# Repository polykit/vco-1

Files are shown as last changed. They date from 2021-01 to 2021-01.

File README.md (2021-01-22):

# Polykit VCO-1

This repository contains schematics and PCB layout for a voltage controlled oscillator (VCO). The goal was to keep price and component count low while having a good 1V/oct tracking. The oscillator core is roughly bases on the Jupiter 8 with a simpler approach for the current sink. It either needs a pair of matched 2N3904 transistors or one BC847BS dual transistor. I have very good results with the BC847BS and an accurate tracking over several octaves. On the output it generates a ramp and a pulse signal with 10Vpp amplitude. There is also a CV input for pulse width modulation.

Note: PCB also contains a simple sub-oscillator with output for one and two octaves down

There is also a PCB version with [eight oscillators on it](https://github.com/polykit/vco-8).

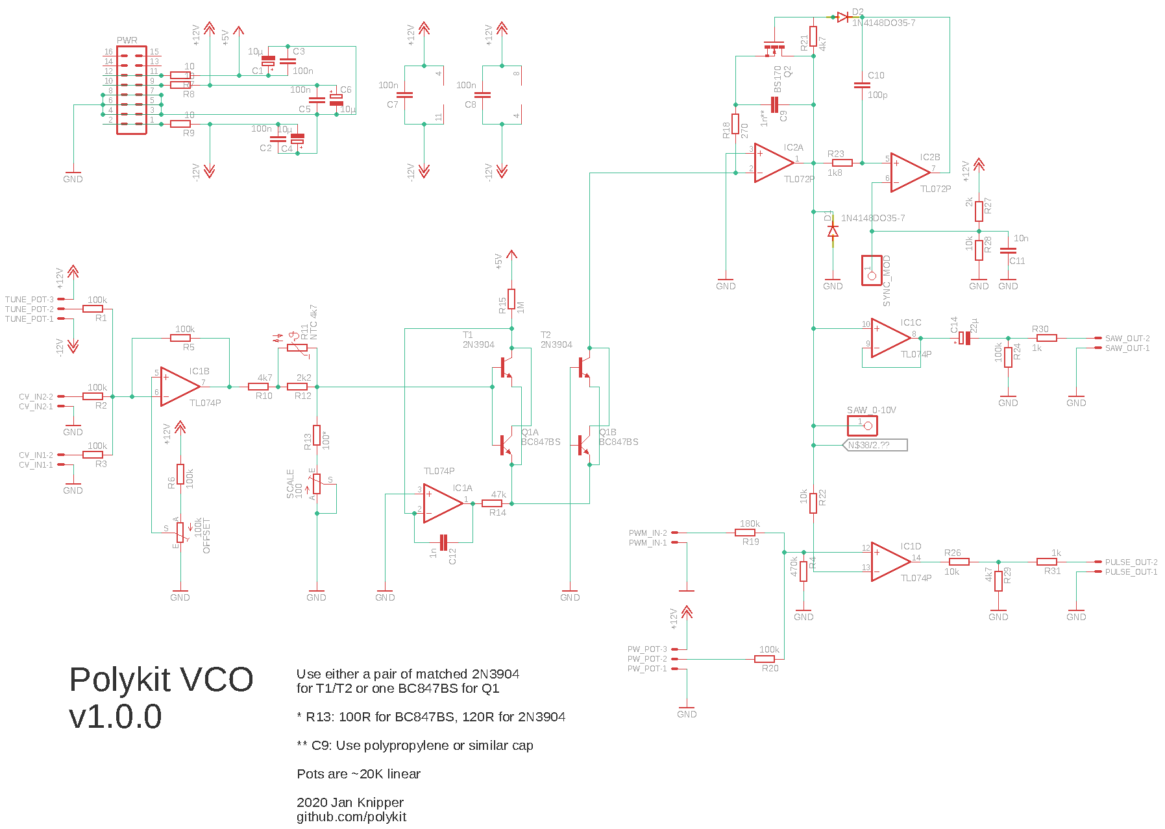
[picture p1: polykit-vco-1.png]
VCO-1 schematics


# References

https://www.muffwiggler.com/forum/viewtopic.php?t=92595

https://kassu2000.blogspot.com/2015/12/vco-part-1-core.html

https://kassu2000.blogspot.com/2015/10/transistor-matching.html

http://www.synthdiy.com/files/2008/RolandJupiter8-ServiceNotes.pdf

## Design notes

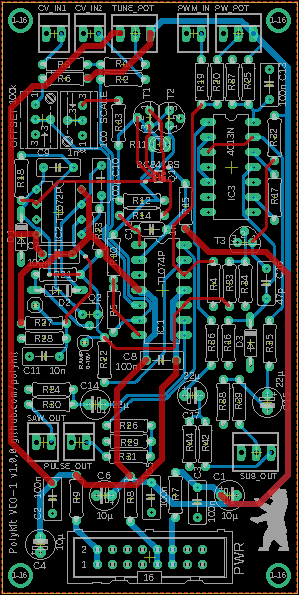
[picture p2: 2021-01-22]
polykit-vco-1-pcb.png

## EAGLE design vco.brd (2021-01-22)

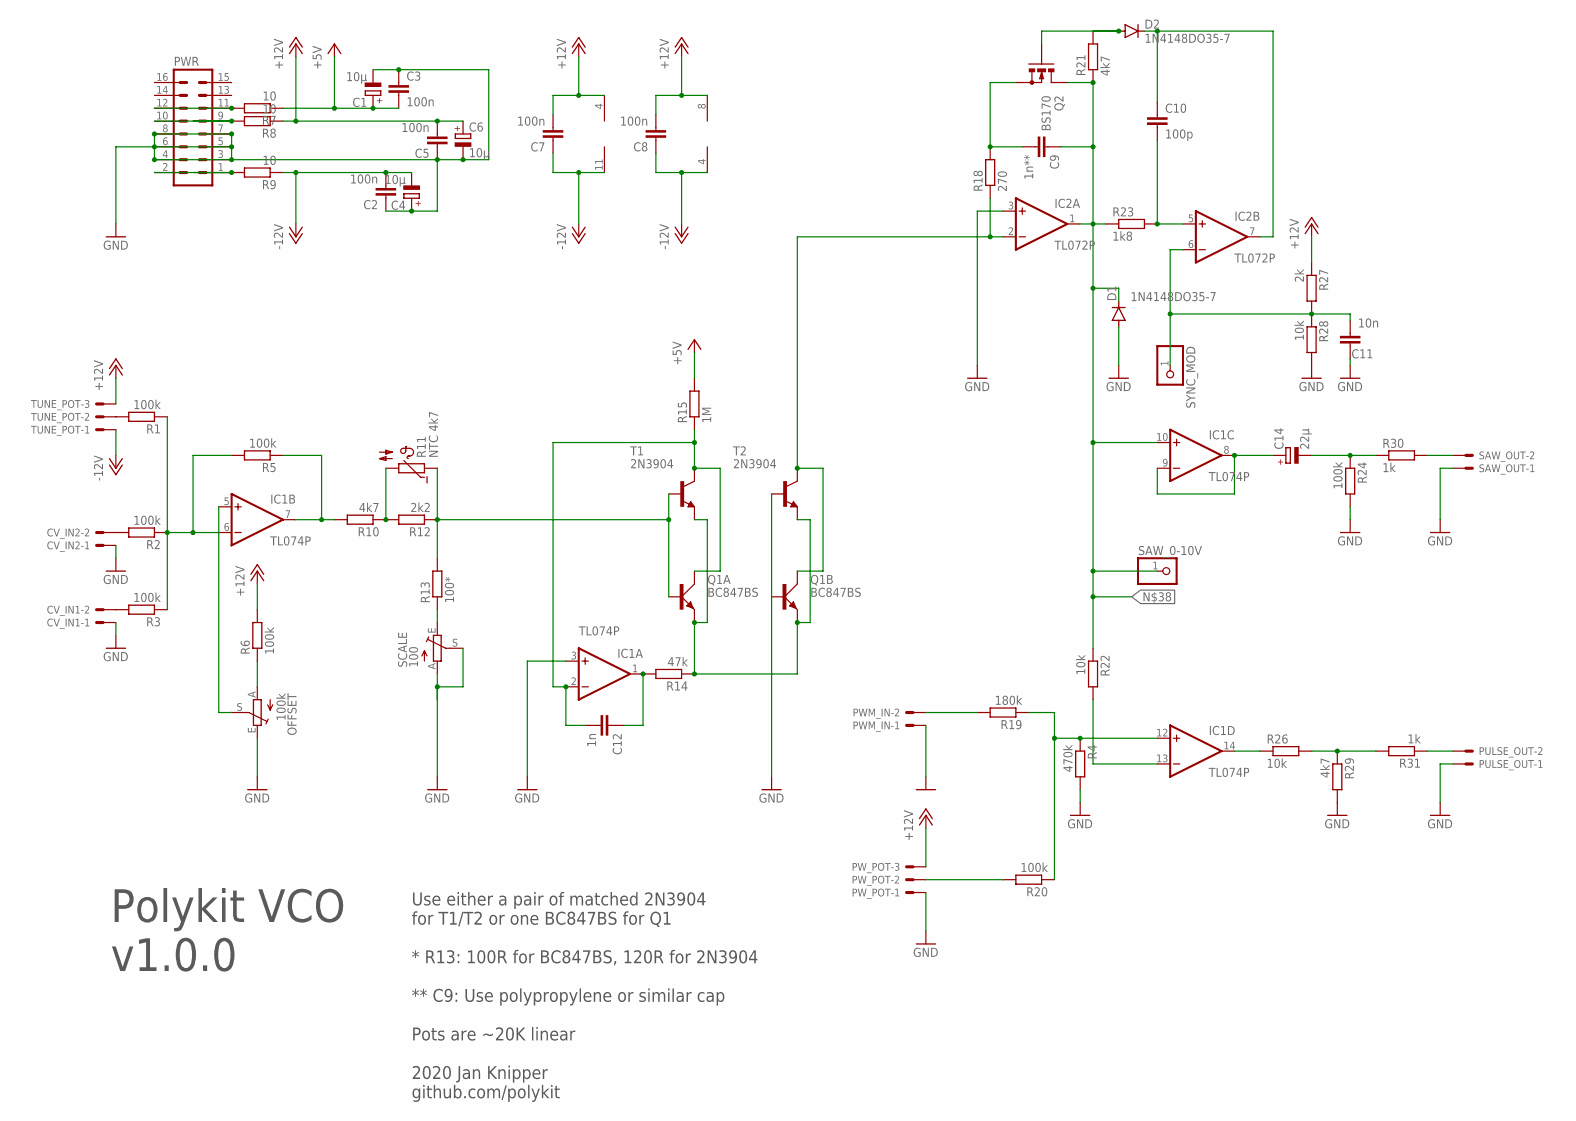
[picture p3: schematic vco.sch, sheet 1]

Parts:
C1, C4, C6: 10µ; E2,5-5
C2, C3, C5, C7, C8: 100n; C050-030X075
C9: 1n**; C050-030X075
C10: 100p; C050-030X075
C11: 10n; C050-030X075
C12: 1n; C050-024X044
C14: 22µ; E2,5-5
CV_IN1, CV_IN2: 22-23-2021
D1, D2: 1N4148DO35-7; DO35-7
IC1: TL074P; DIL14
IC2: TL072P; DIL08
OFFSET: 100k; S64YW
PULSE_OUT: 22-23-2021
PWM_IN: 22-23-2021
PWR: ML16
PW_POT: 22-23-2031
Q1: BC847BS; SOT363_PHILIPS
Q2: BS170; SOT54E
R1, R2, R3, R5, R6, R20, R24: 100k; 0207/7
R4: 470k; 0207/7
R7, R8, R9: 10; 0207/7
R10, R21, R29: 4k7; 0207/7
R11: NTC 4k7; P640
R12: 2k2; 0207/7
R13: 100*; 0207/7
R14: 47k; 0207/7
R15: 1M; 0207/7
R18: 270; 0207/7
R19: 180k; 0207/7
R22, R26, R28: 10k; 0207/7
R23: 1k8; 0207/7
R27: 2k; 0207/7
R30, R31: 1k; 0207/7
SAW_0-10V: PINHD-1X1; 1X01
SAW_OUT: 22-23-2021
SCALE: 100; S64YW
SYNC_MOD: PINHD-1X1; 1X01
T1, T2: 2N3904; TO92
TUNE_POT: 22-23-2031

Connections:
+5V: C1.+, C3.2, R7.1, R15.2
+12V: C5.2, C6.+, C7.2, C8.2, IC1.4 (V+), IC2.8 (V+), PW_POT.3, R6.2, R8.1, R27.1, TUNE_POT.3; also elsewhere on the board
-12V: C2.2, C4.-, C7.1, C8.1, IC1.11 (V-), IC2.4 (V-), R9.1, TUNE_POT.1
GND: C1.-, C2.1, C3.1, C4.+, C5.1, C6.-, C11.1, CV_IN1.1, CV_IN2.1, D1.A, IC1.3 (+IN), IC2.3 (+IN), OFFSET.E, PULSE_OUT.1, PWM_IN.1, PWR.3, PWR.4, PWR.5, PWR.6, PWR.7, PWR.8, PW_POT.1, Q1.5 (B), R4.2, R24.2, R28.2, R29.2, SAW_OUT.1, SCALE.A, SCALE.S, T2.2 (B); also elsewhere on the board
unnamed: PWR.1, PWR.2, R9.2
unnamed: Q1.1 (E), Q1.4 (E), R14.1, T1.3 (E), T2.3 (E)
unnamed: C12.2, IC1.2 (-IN), Q1.6 (C), R15.1, T1.1 (C)
unnamed: PWR.9, PWR.10, R8.2
unnamed: Q1.2 (B), R11.1, R12.1, R13.2, T1.2 (B)
unnamed: C14.-, R24.1, R30.1
unnamed: PULSE_OUT.2, R31.1
unnamed: IC1.7 (OUT), R5.1, R10.2
unnamed: R1.2, TUNE_POT.2
unnamed: C10.1, D2.C, IC2.7 (OUT)
unnamed: OFFSET.A, R6.1
unnamed: CV_IN2.2, R2.2
unnamed: CV_IN1.2, R3.2
unnamed: C14.+, IC1.8 (OUT), IC1.9 (-IN)
unnamed: R30.2, SAW_OUT.2
unnamed: IC1.13 (-IN), R22.2
unnamed: IC1.14 (OUT), R26.1
unnamed: R26.2, R29.1, R31.2
unnamed: IC1.12 (+IN), R4.1, R19.1, R20.1
unnamed: PWM_IN.2, R19.2
unnamed: PW_POT.2, R20.2
unnamed: IC1.5 (+IN), OFFSET.S
unnamed: R10.1, R11.2, R12.2
unnamed: C10.2, IC2.5 (+IN), R23.2
unnamed: PWR.11, PWR.12, R7.2
unnamed: C12.1, IC1.1 (OUT), R14.2
unnamed: C9.2, Q2.S, R18.2
unnamed: D2.A, Q2.G, R21.2
unnamed 41: C9.1, D1.C, IC1.10 (+IN), IC2.1 (OUT), Q2.D, R21.1, R22.1, R23.1, SAW_0-10V.1; also elsewhere on the board
unnamed: C11.2, IC2.6 (-IN), R27.2, R28.1, SYNC_MOD.1
unnamed: IC2.2 (-IN), Q1.3 (C), R18.1, T2.1 (C)
unnamed: R13.1, SCALE.E
unnamed: IC1.6 (-IN), R1.1, R2.1, R3.1, R5.2

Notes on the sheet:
Use either a pair of matched 2N3904 for T1/T2 or one BC847BS for Q1 * R13: 100R for BC847BS, 120R for 2N3904 ** C9: Use polypropylene or similar cap Pots are ~20K linear 2020 Jan Knipper github.com/polykit
Polykit VCO v1.0.0

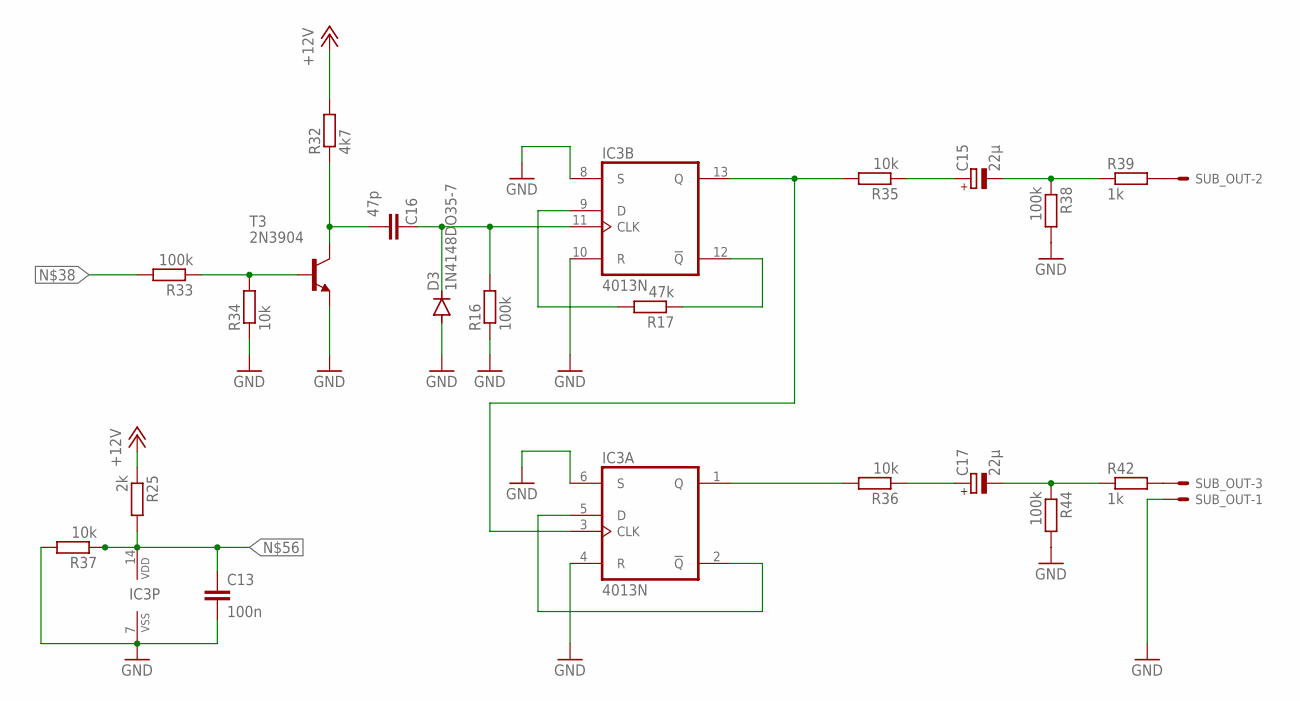
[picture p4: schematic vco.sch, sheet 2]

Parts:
C13: 100n; C050-030X075
C15, C17: 22µ; E2,5-5
C16: 47p; C050-030X075
D3: 1N4148DO35-7; DO35-7
IC3: 4013N; DIL14
R16, R33, R38, R44: 100k; 0207/7
R17: 47k; 0207/7
R25: 2k; 0207/7
R32: 4k7; 0207/7
R34, R35, R36, R37: 10k; 0207/7
R39, R42: 1k; 0207/7
SUB_OUT: 22-23-2031
T3: 2N3904; TO92

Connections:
+12V: R25.1, R32.2; also elsewhere on the board
GND: C13.2, D3.A, IC3.4 (R), IC3.6 (S), IC3.7 (VSS), IC3.8 (S), IC3.10 (R), R16.1, R34.1, R37.2, R38.2, R44.2, SUB_OUT.1, T3.3 (E); also elsewhere on the board
unnamed: R42.2, SUB_OUT.3
unnamed: R33.1, R34.2, T3.2 (B)
unnamed: C16.1, D3.C, IC3.11 (CLK), R16.2
unnamed: IC3.9 (D), R17.2
unnamed: IC3.12 (!Q), R17.1
unnamed: C16.2, R32.1, T3.1 (C)
unnamed: C15.+, R35.1
unnamed: C15.-, R38.1, R39.1
unnamed 41: R33.2; also elsewhere on the board
unnamed: IC3.2 (!Q), IC3.5 (D)
unnamed: IC3.3 (CLK), IC3.13 (Q), R35.2
unnamed: IC3.1 (Q), R36.2
unnamed: C17.+, R36.1
unnamed: R39.2, SUB_OUT.2
unnamed: C17.-, R42.1, R44.1
unnamed: C13.1, IC3.14 (VDD), R25.2, R37.1

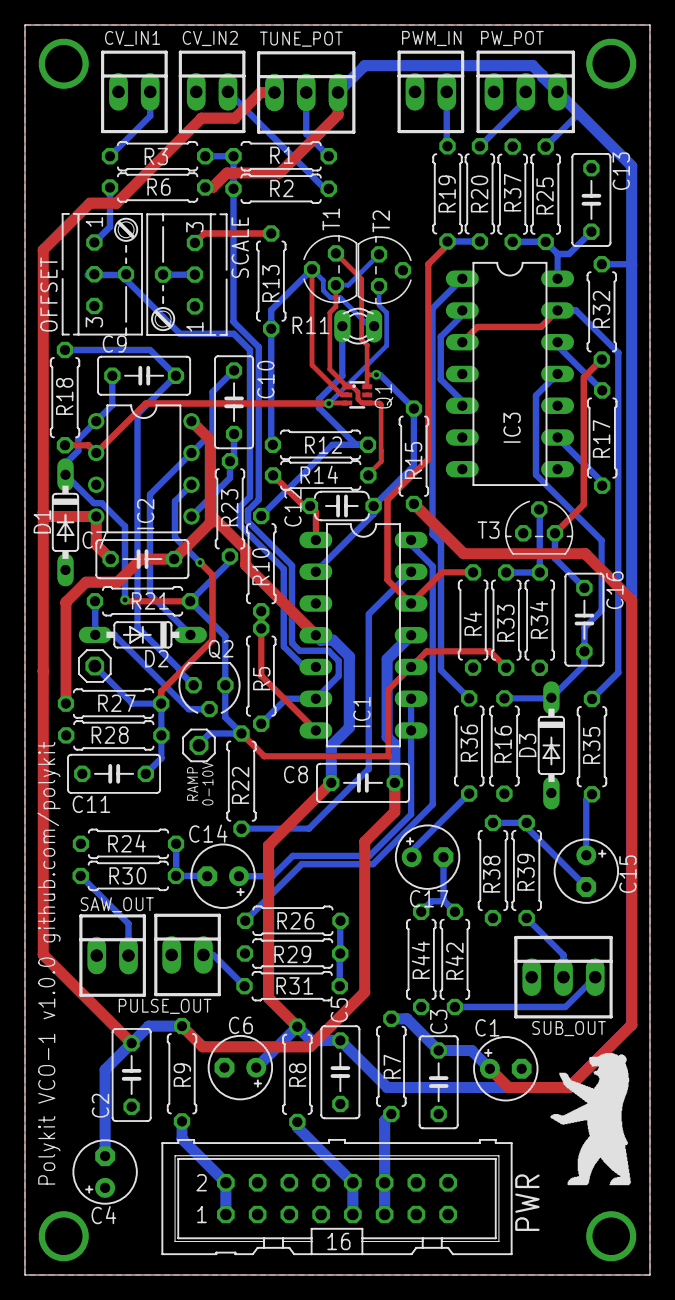
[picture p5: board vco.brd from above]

Board: 2 copper layers, 50.0 x 100.0 mm, 82 parts (0 on the bottom side), 52 nets.
